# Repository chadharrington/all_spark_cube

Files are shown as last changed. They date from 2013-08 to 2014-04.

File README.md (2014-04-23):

## General Cube Info

The All Spark Cube was built in 2012-2013 by Adaptive Computing and friends. More 
info is available here:
* www.allsparkcube.com
* [Hackaday Article](http://hackaday.com/2012/10/21/4096-leds-means-the-biggest-led-cube-ever/)

## Cube Client Libraries

To interact with the All Spark Cube, you'll need a client library for your 
preferred programming language. There are currently cube client libraries 
available for Python and Java. Skip to the relevant section for your language.

### Python Client 

#### Usage
Here is the Python [Hello World](https://github.com/chadharrington/all_spark_cube/blob/master/software/clients/python_client/examples/helloworld.py) demo:
```
#!/usr/bin/env python

from all_spark_cube_client import CubeClient, Color, Colors

#HOST = 'localhost'
HOST = 'cube.ac'
PORT = 12345

client = CubeClient(HOST, PORT)

# Built-in colors are: red, green, blue, yellow, cyan, magenta, 
# white, black, gray, orange, pink, light_yellow, and dark_green
# You can also create any arbitrary color by creating an instance 
# of the Color class with the R, G, and B values specified.

# Set all LEDs to blue. 
client.set_all_leds(Colors.blue)

# Set the first LED (#0) to red
client.set_led(0, Colors.red)

# Set the second LED (#1) to a custom color (teal-ish)
client.set_led(1, Color(100, 255, 95))

# Starting at LED #48, set 16 LEDs to yellow
client.set_led_range(48, 16, Colors.yellow)

# Set the last LED (#4095) to green
client.set_led(4095, Colors.green)

# Actually send the data to the cube
client.send();  

print 'Success...'
```

#### Installation

Install the [Python client library](https://pypi.python.org/pypi/all_spark_cube_client/)
using pip. If you don't have pip installed, get it 
[here.](http://www.pip-installer.org/en/latest/installing.html)

`$ pip install all_spark_cube_client`

You can safely ignore the 10 or so warnings generated by pip, these are a 
part of the underlying [Thrift](http://thrift.apache.org/) library, and don't
affect the cube client library.

Download the code and run the [Hello World](https://github.com/chadharrington/all_spark_cube/blob/master/software/clients/python_client/examples/helloworld.py) demo on the cube:

```
$ wget -O helloworld.py http://git.io/hellopycube
$ python helloworld.py
```

You should see the cube change colors as specified in the program (first LED 
red, second LED teal, a row of yellow LEDs, etc.) You should see 
"Success..." on your command line. If you get errors instead, open the 
helloworld.py file and make sure the HOST 
parameter is set to the correct network address for the cube. You should also
make sure the cube is turned on and reachable over the network.

### Java Client 

#### Usage
The Java [Hello World](https://github.com/chadharrington/all_spark_cube/blob/master/software/clients/java_client/examples/HelloWorld.java) demo is below. Note that the API uses the [java.awt.Color](http://docs.oracle.com/javase/7/docs/api/java/awt/Color.html) class to specify colors for the LEDs.
```
import java.awt.Color;

import com.allsparkcube.CubeClient;
import org.apache.thrift.TException;

public class HelloWorld {
    public static void main(String[] args) {
        try {

            // final String HOST = "localhost";
            final String HOST = "cube.ac";
            final int PORT = 12345;
        
            CubeClient client = new CubeClient(HOST, PORT);

            // Set all LEDs to blue
            client.setAllLeds(Color.white); 

            // Set the first LED (#0) to red
            client.setLed(0, Color.red);

            // Set the second LED (#1) to a custom color (teal-ish)
            Color teal = new Color(100, 255, 95);
            client.setLed(1, teal);
        
            // Starting at LED #48, set 16 LEDs to yellow
            client.setLedRange(48, 16, Color.yellow); 

            // Set the last LED (#4095) to green
            client.setLed(4095, Color.green);
        
            // Actually send the data to the cube
            client.send();  
        
            System.out.println("Success...");
        } catch (TException e) {
            e.printStackTrace();
        }
    }
}

``` 

#### Installation
You can install and use the Java client with or without Maven.

##### Using Maven
Clone the git repository, then build  and run the [Hello World](https://github.com/chadharrington/all_spark_cube/blob/master/software/clients/java_client/examples/HelloWorld.java) example using Maven:

```
$ git clone https://github.com/chadharrington/all_spark_cube.git
$ cd all_spark_cube/software/clients/java_client/examples/
$ mvn package
$ cd target/com/mycompany
$ java -cp hello-world-0.1-standalone.jar HelloWorld
```
You should see the cube change colors as specified in the program (first LED 
red, second LED teal, a row of yellow LEDs, etc.) You should see 
"Success..." on your command line. If you get errors instead, open the 
HelloWorld.java file and make sure the HOST 
parameter is set to the correct network address for the cube. You should also
make sure the cube is turned on and reachable over the network.

#### Direct Download 
If you don't use Maven, you can download the client jar and [Hello World](https://github.com/chadharrington/all_spark_cube/blob/master/software/clients/java_client/examples/HelloWorld.java) example directly from GitHub:

```
$ wget http://git.io/cubejar -O cube_client-0.6-standalone.jar
$ wget http://git.io/hellojavacube -O HelloWorld.java 
$ javac -cp .:cube_client-0.6-standalone.jar HelloWorld.java
$ java -cp .:cube_client-0.6-standalone.jar HelloWorld
```

You should see the cube change colors as specified in the program (first LED 
red, second LED teal, a row of yellow LEDs, etc.) You should see 
"Success..." on your command line. If you get errors instead, open the 
HelloWorld.java file and make sure the HOST 
parameter is set to the correct network address for the cube. You should also
make sure the cube is turned on and reachable over the network.

## Cube Server Install
These instructions are only relevant for installing the server onto the computer 
inside the All Spark Cube. Cube users need not install the server code.

The server code and these instructions assume a CentOS / RHEL server.

1 - Install supervisor from http://supervisord.org
2 - Run these commands:

```    
$ git clone https://github.com/chadharrington/all_spark_cube.git
$ cd all_spark_cube/software/server
$ sudo make install
$ sudo reboot now
```

The server will automatically start on reboot / powerup. If everything installed
correctly, the cube should display all white LEDs after booting.

## Support

Having trouble? [Open an issue](https://github.com/chadharrington/all_spark_cube/issues).

## License

All code in this repository is licensed under an MIT license.

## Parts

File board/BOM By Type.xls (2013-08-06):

RefDes | Quantity | Digikey PN | Type | Value | Manufacturer | Manufacturer PN
C3, C4, C5, C6, C25, C26 | 26 | 399-8140-1-ND | CAP_1206 | 0.1 uF | Keme | C1206C104K3RACTU
C27 | 1 | 399-1255-1-ND | CAP_1206 | 1 uF | Keme | C1206C105K3RACTU
C28 | 1 | 399-10116-1-ND | CAP_1206 | 10 uF Tantalum | Kemet | T491A106K006AT7280
D1, D2, D3, D4 | 4 | 67-1685-1-ND | GRN SMD LED |  | Lumex | SML-LX15GC-TR
F1 | 1 | 3544-2K-ND | Fuse Holder |  | Keystone Electronics | 3544-2
H1, H2, H3, H4 | 4 |  | 0.125 Mnt Hole
J2, J3, J13, J14, J15, J16 | 16 |  | 0.1SMT 2x8ML |  | Samtec | TSM-108-0-S-DV
J17 | 1 | WM7243-ND | 6POS PWR JACK |  | Molex | 39294069
Q1, Q2, Q3, Q4, Q5, Q6, Q7, Q8, Q9, Q10, Q11, Q12, Q13, Q14, Q15, Q16 | 16 | FDS4465CT-ND | PFET |  | Fairchild Semiconductor | FDS4465
R7, R8, R9, R10 | 24 | 311-158FRCT-ND | RES_1206 | 158R | Yageo | RC1206FR-07158RL
R25, R26 | 2 | RMCF1206FT100KCT-ND | RES_1206 | 100K | Stackpole Eletronic | RMCF1206FT100K
R27 | 1 | 311-1.47KFRCT-ND | RES_1206 | 1K47 | Yageo | RC1206FR-071K47L
R28 | 1 | RMCF1206FT324RCT-ND | RES_1206 | 324R | Stackpole Eletronic | RMCF1206FTxxxx
R29, R30 | 2 | RMCF1206FT499RCT-ND | RES_1206 | 499R | Stackpole Eletronic | RMCF1206FTxxxx
R31 | 1 | RMCF1206FT105RCT-ND | RES_1206 | 105R | Stackpole Eletronic | RMCF1206FTxxxx
R32 | 1 | RMCF1206FT140RCT-ND | RES_1206 | 140R | Stackpole Eletronic | RMCF1206FT140R
RN1, RN2 | 8 | 4816P-1-100LFCT-ND | Resistor Pack | 10R | Bourns, Inc. | 4816P-1-100LF
RN9, RN10 | 2 | 4816P-1-104LFCT-ND | Resistor Pack | 100K | Bourns | 4816P-1-104LF
S1, S2, S3, S4 | 4 | SW1030CT-ND | Rotary Hex Switch |  | Omron | A6RS-161RS-P
U4, U5, U6, U7 | 24 | 296-21995-1-ND | TLC5917 |  | TI | TLC5917IDR
U25, U26, U27 | 3 | 296-21928-1-ND | Level Tranaslator |  | TI | TXB0104DR
U28 | 1 | P0082-ND | DE0-Nano |  | Terasic | P0082
U29 | 1 | 555-1051-ND | 3A Adj POL |  | Lineage Power | AXA003A0XZ
U30 | 1 | 941-1045-ND | 40A Adj POL |  | Delta | D12F200A
U31 | 1 | 768-1103-ND | UM232H |  | FTDI | UM232H
 | 147

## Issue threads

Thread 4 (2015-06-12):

Help

petreg, 2015-06-12:
First, sorry, my English is very bad and I'm using Google translator.
I would like to know how to assemble the circuit LEDs. I can not understand how to put together the 4096 leds with all RGBs connector. And I want to take a doubt, the data in this Github project, he used to program the de0-nano also? Yes I know I just need to ask you build a cube allspak for me, but if you can help me I would create a allsaprk for me.
>Thank you.

chadharrington, 2015-06-12:
Hi @petreg,
Building a large cube like we did might not be a good idea.  The 16x16x16 RGB cube cost around $10K to build and took a man-year or more. We also don't have time to document the build process, as it is very complicated. Here are some other LED cube projects with very good documentation:
- 4x4x4 RGB cube: http://www.instructables.com/id/4x4x4-RGB-LED-Cube/?ALLSTEPS
- 8x8x8 monochrome cube: http://www.instructables.com/id/Led-Cube-8x8x8/?ALLSTEPS
- 8x8x8 RGB cube: http://www.instructables.com/id/8X8X8-RGB-LED-Cube/?ALLSTEPS

Closed 2015-06-12.

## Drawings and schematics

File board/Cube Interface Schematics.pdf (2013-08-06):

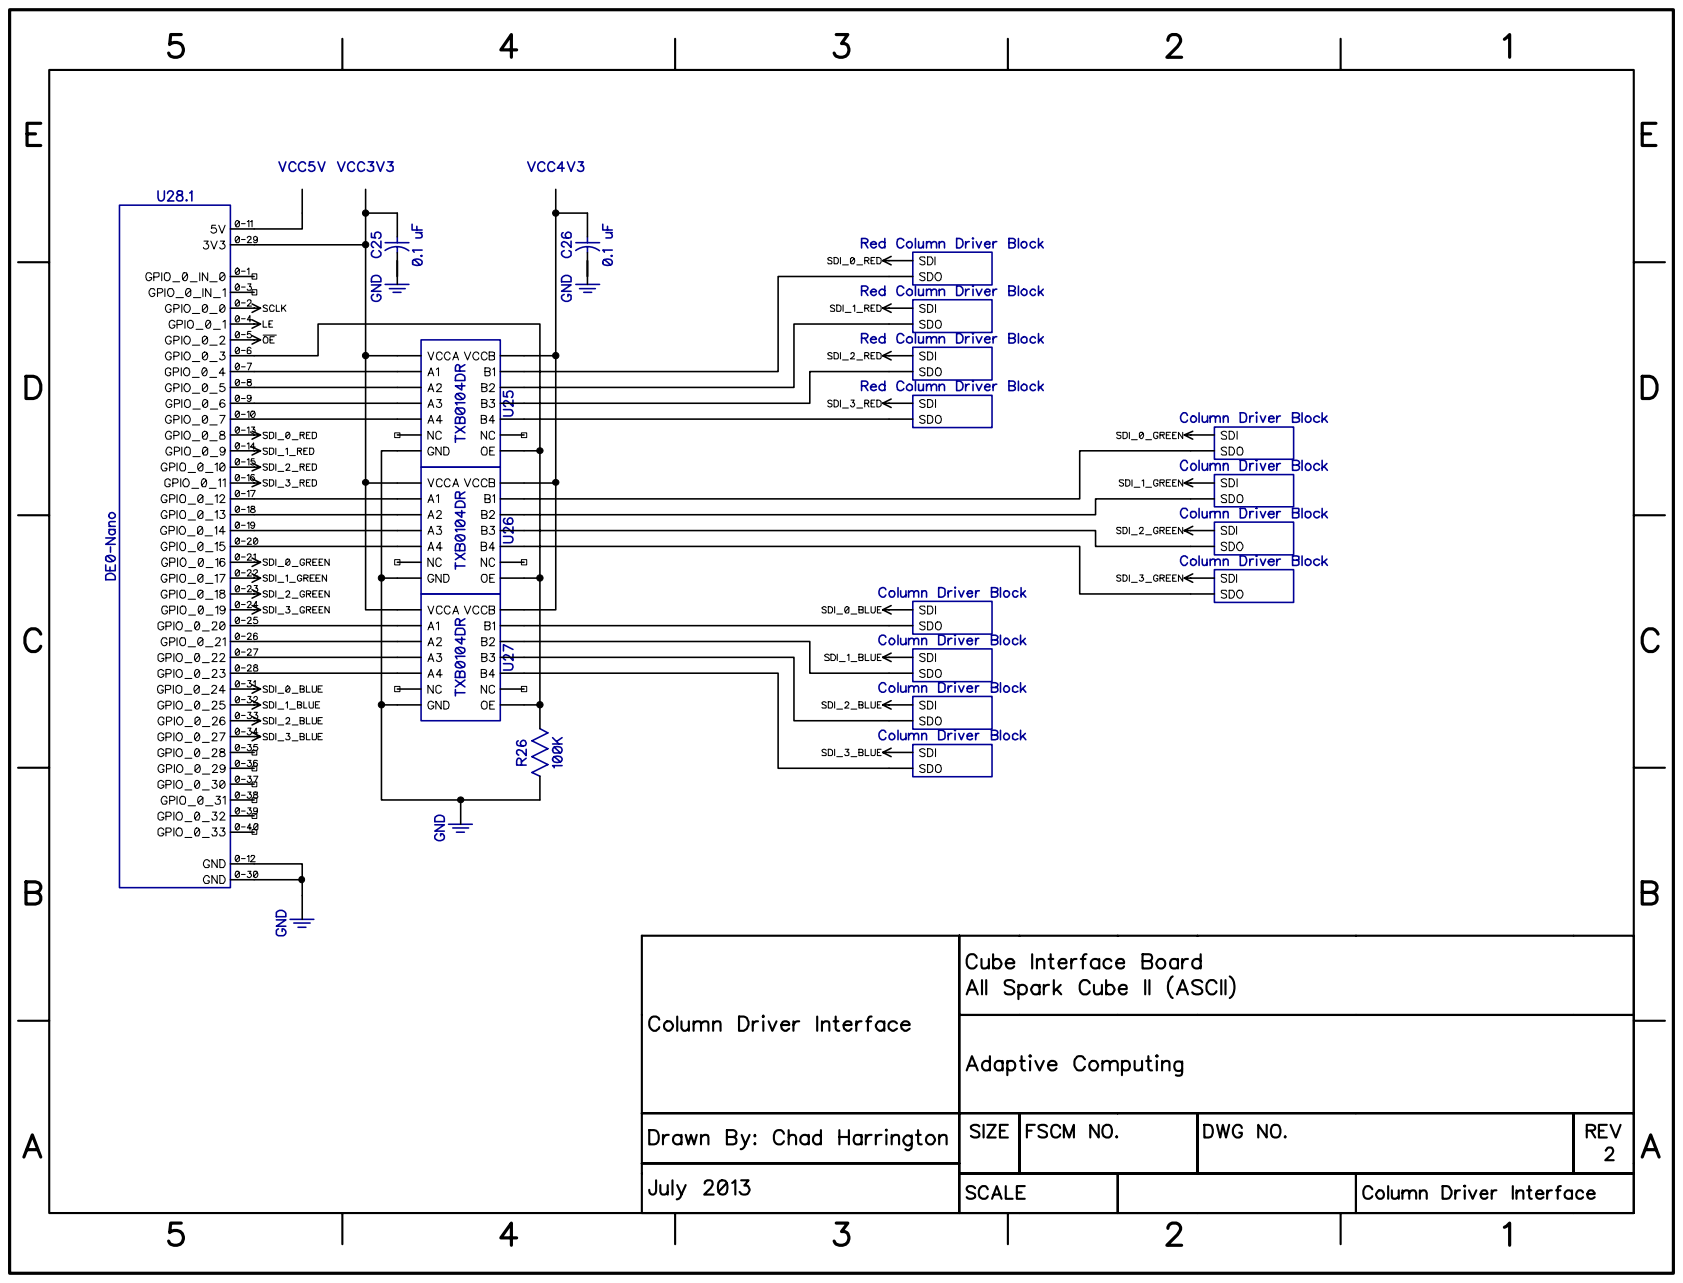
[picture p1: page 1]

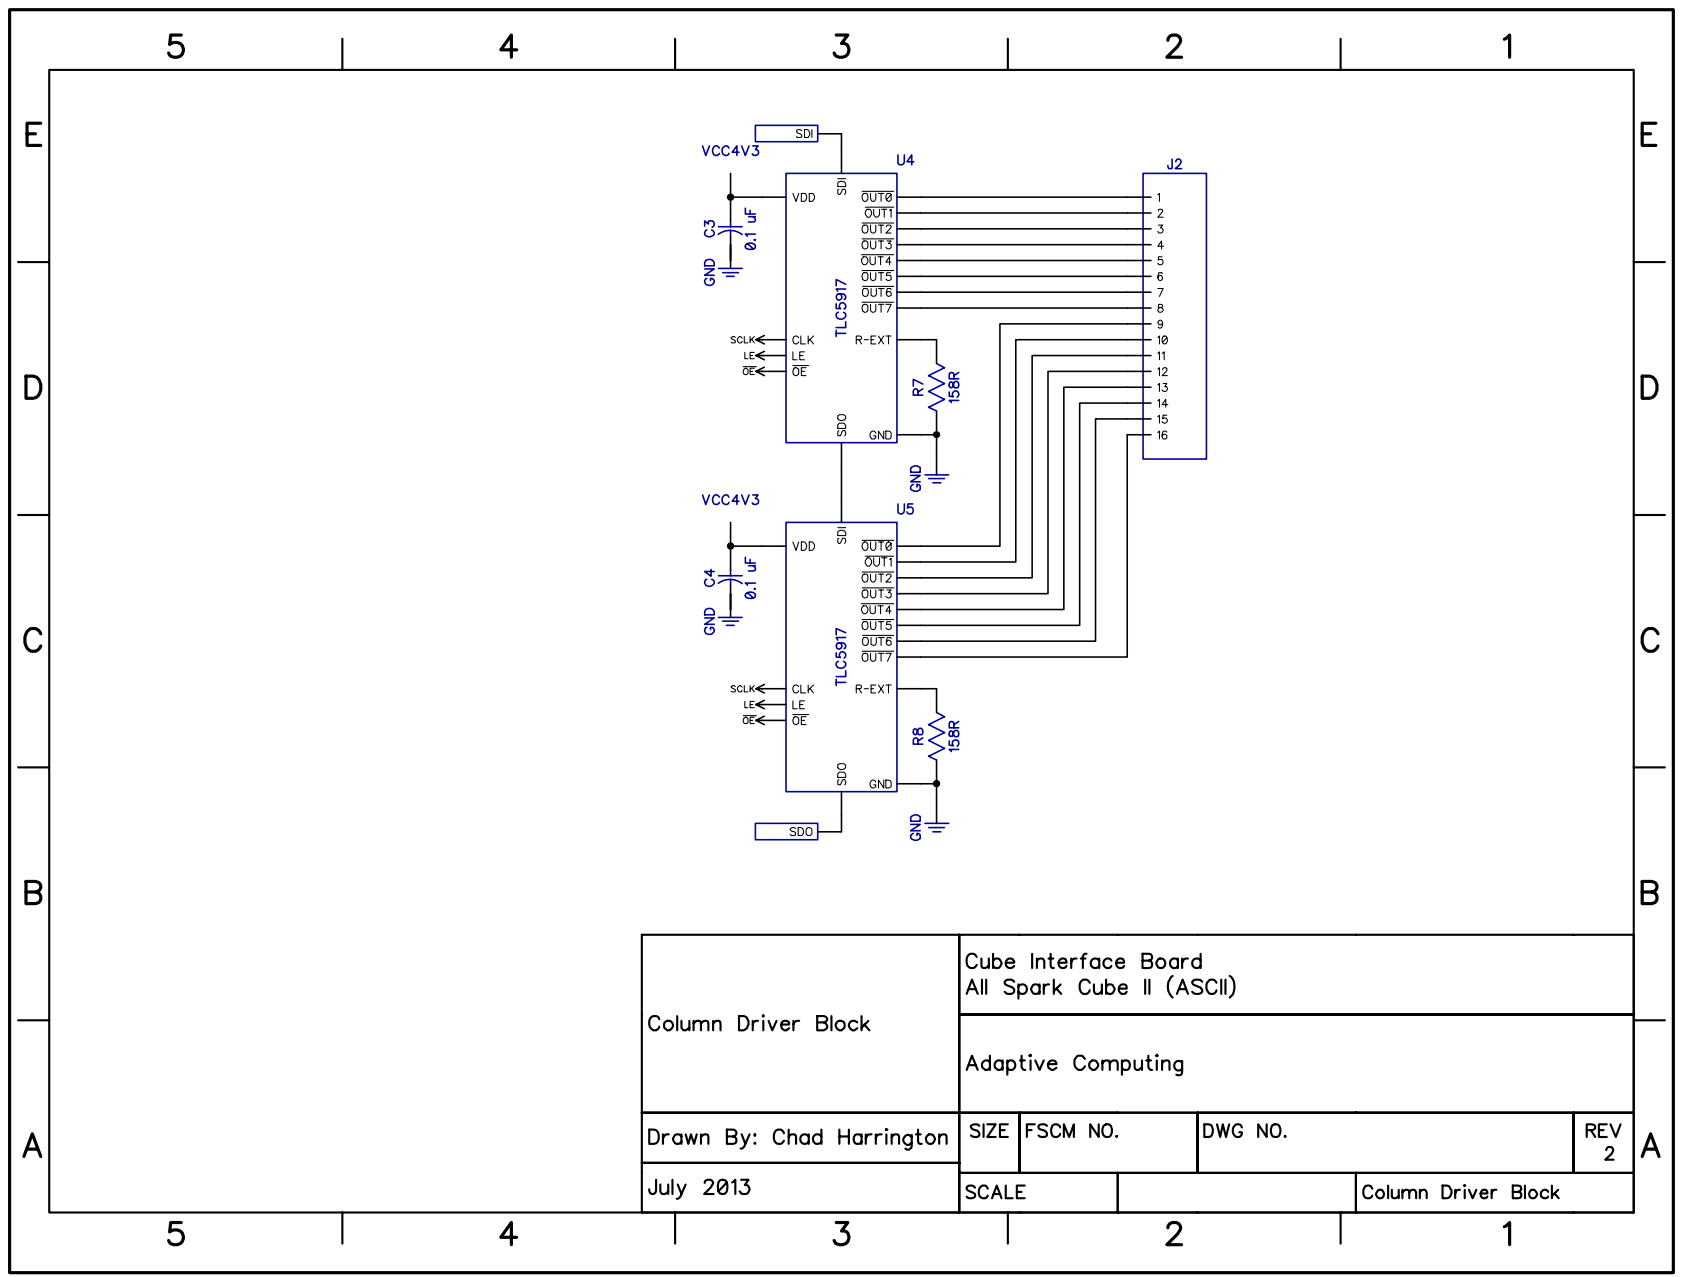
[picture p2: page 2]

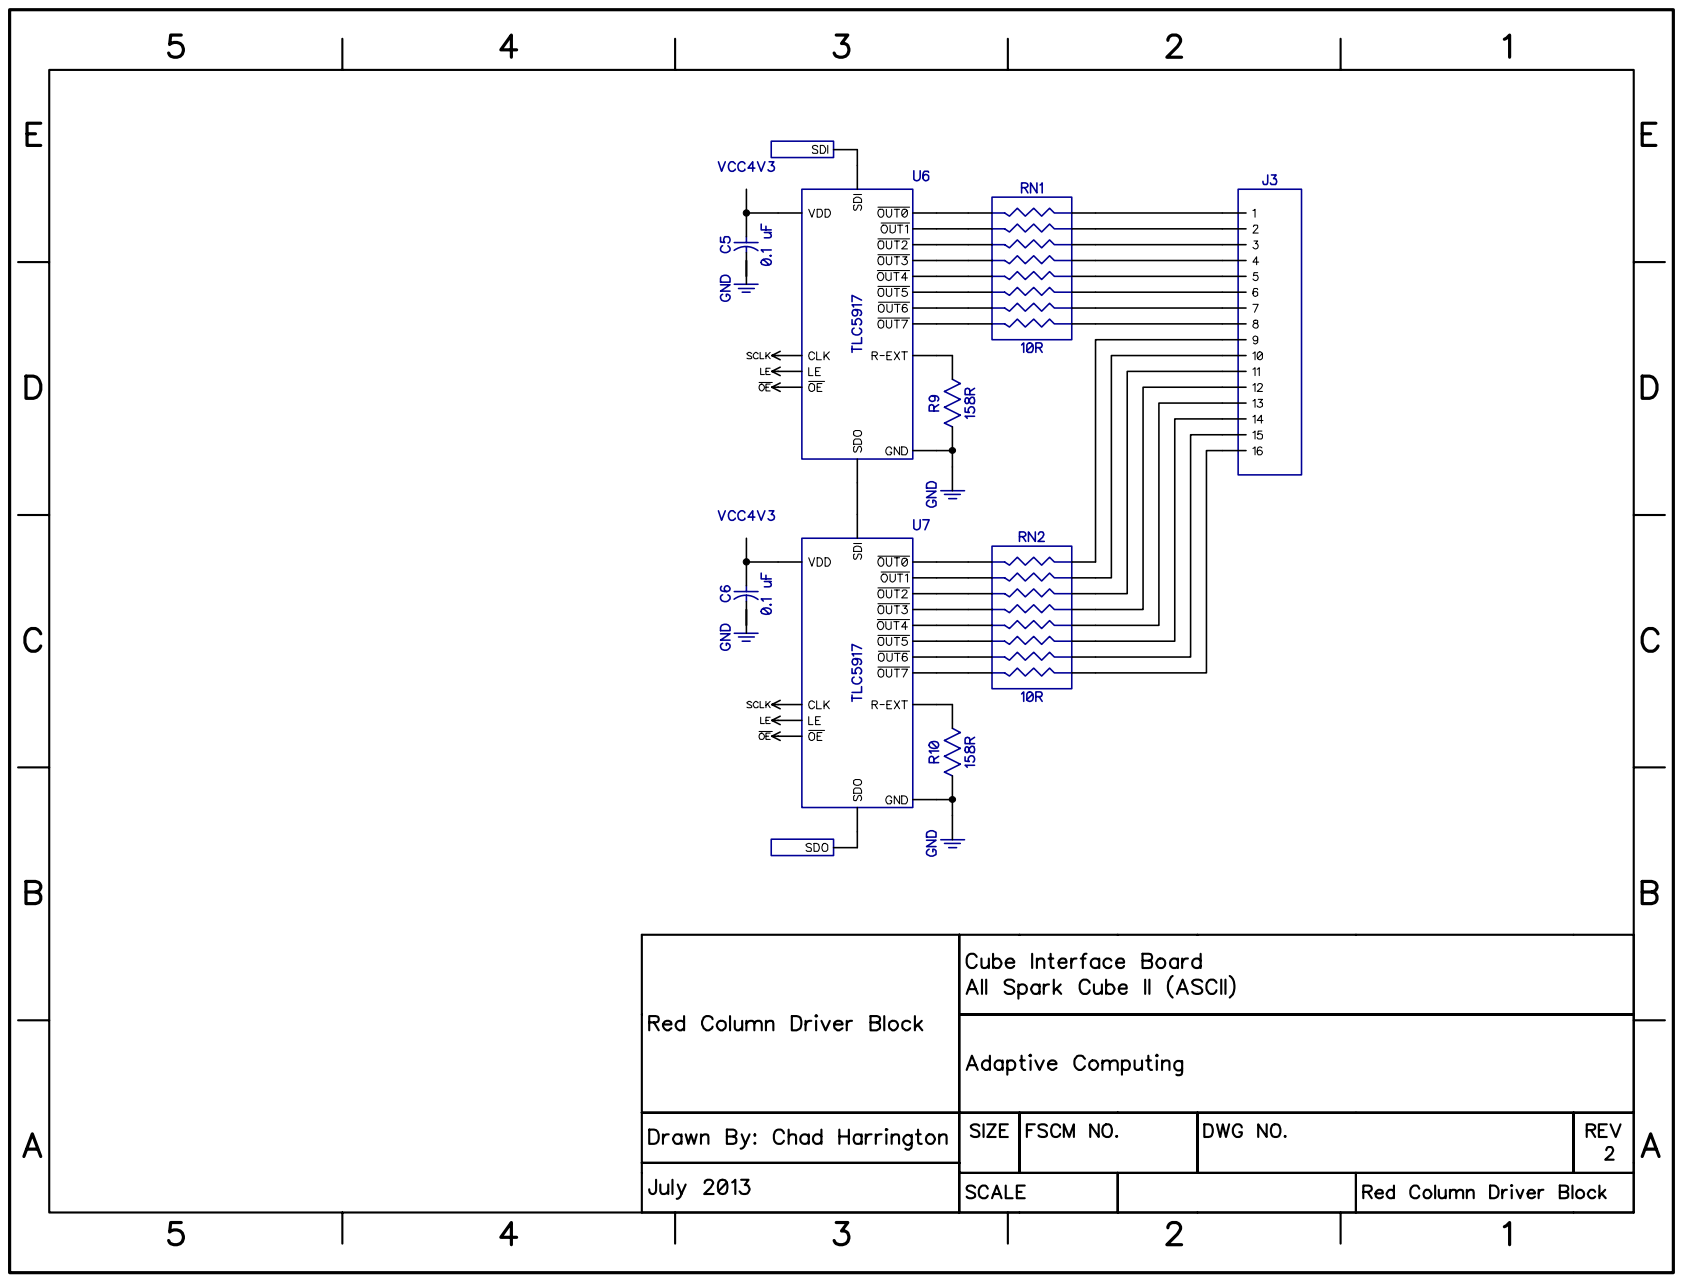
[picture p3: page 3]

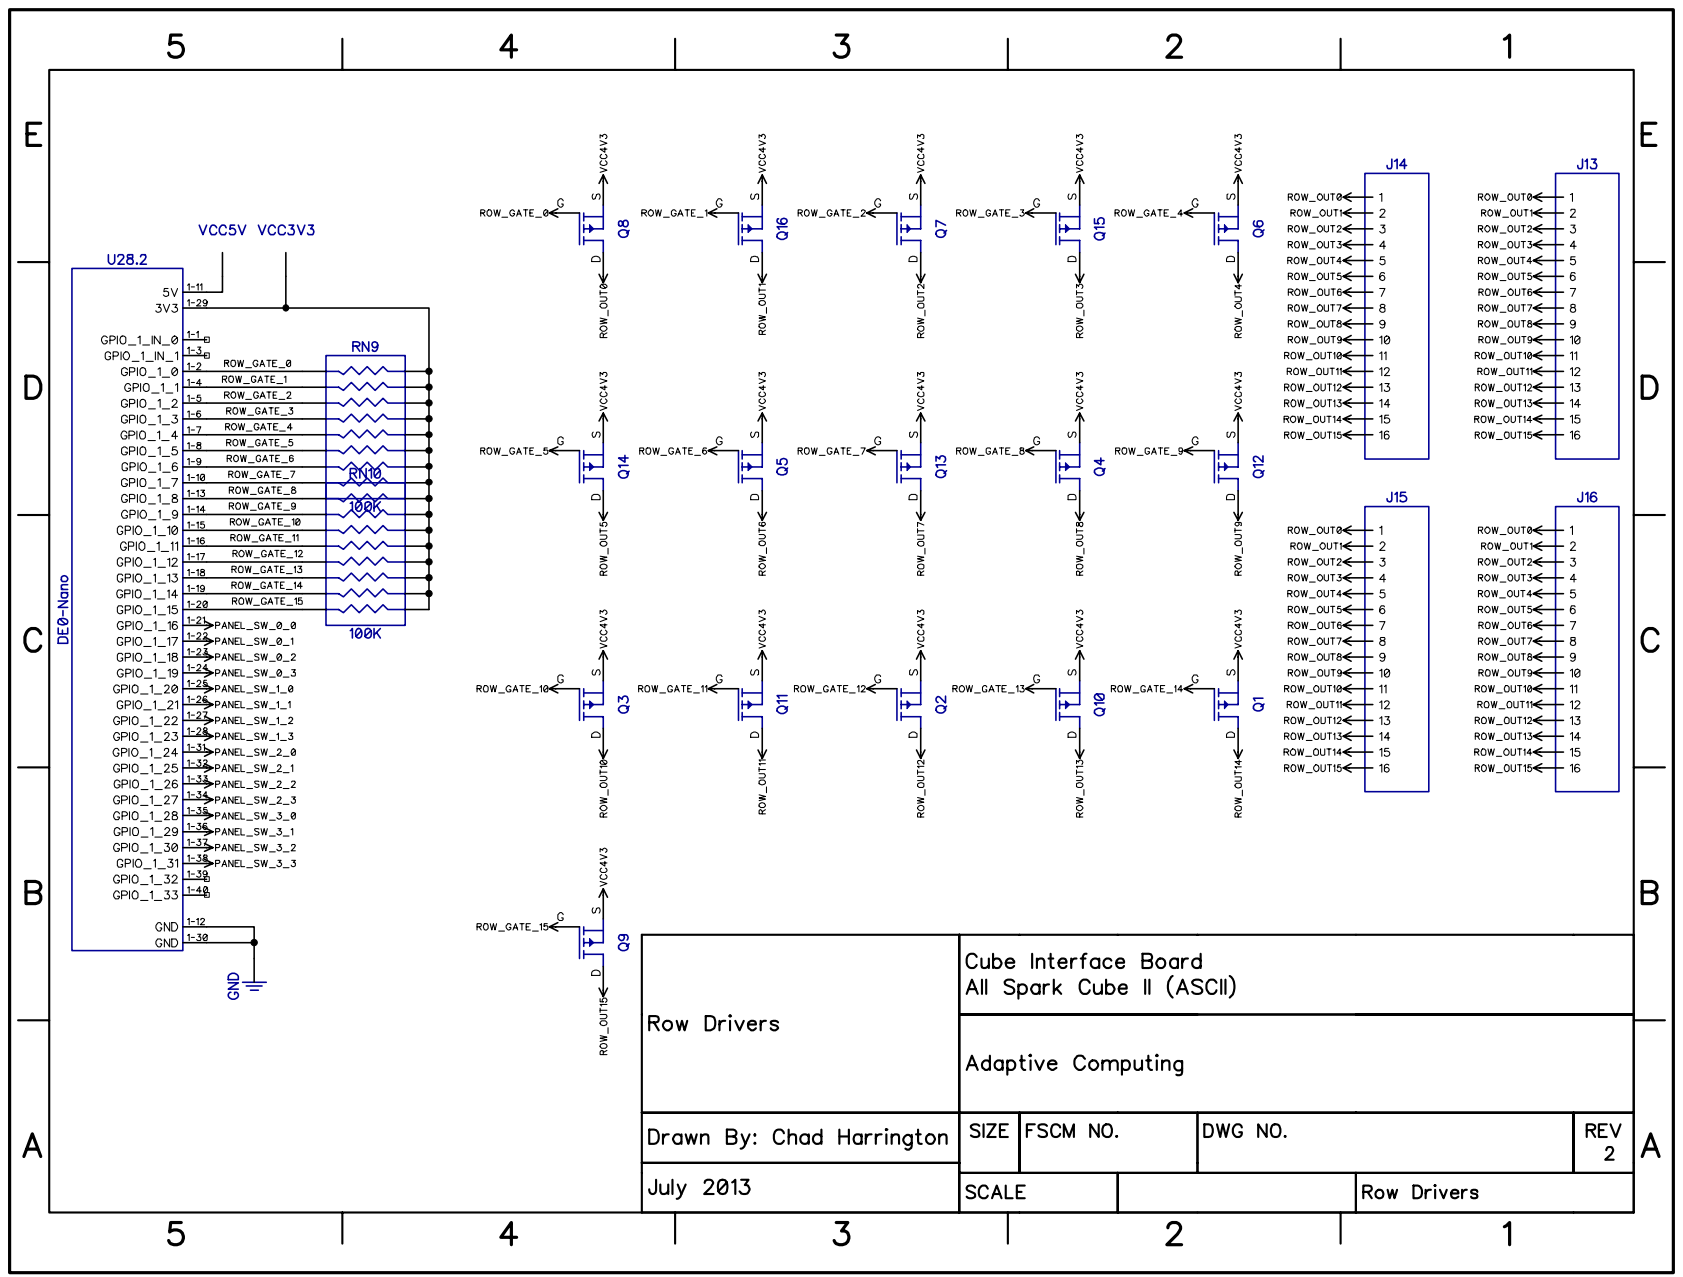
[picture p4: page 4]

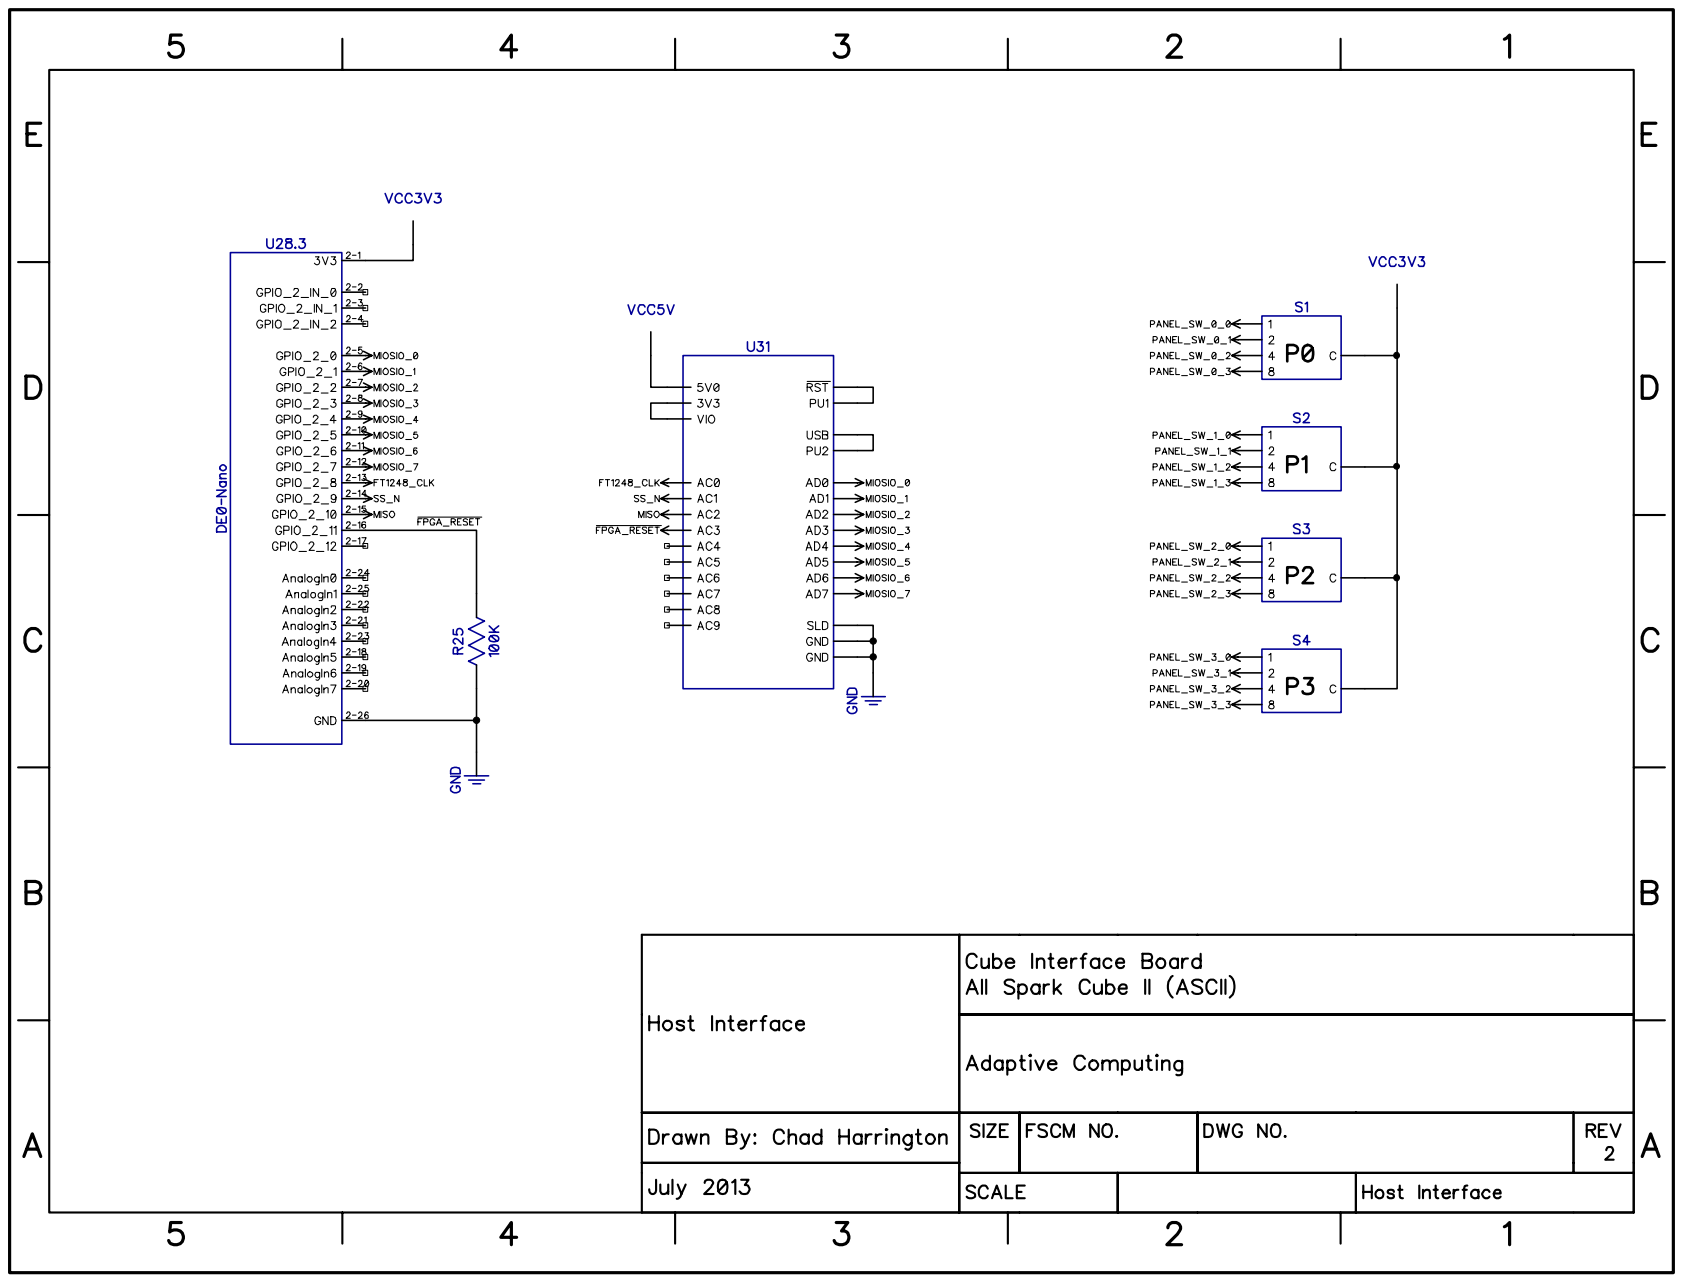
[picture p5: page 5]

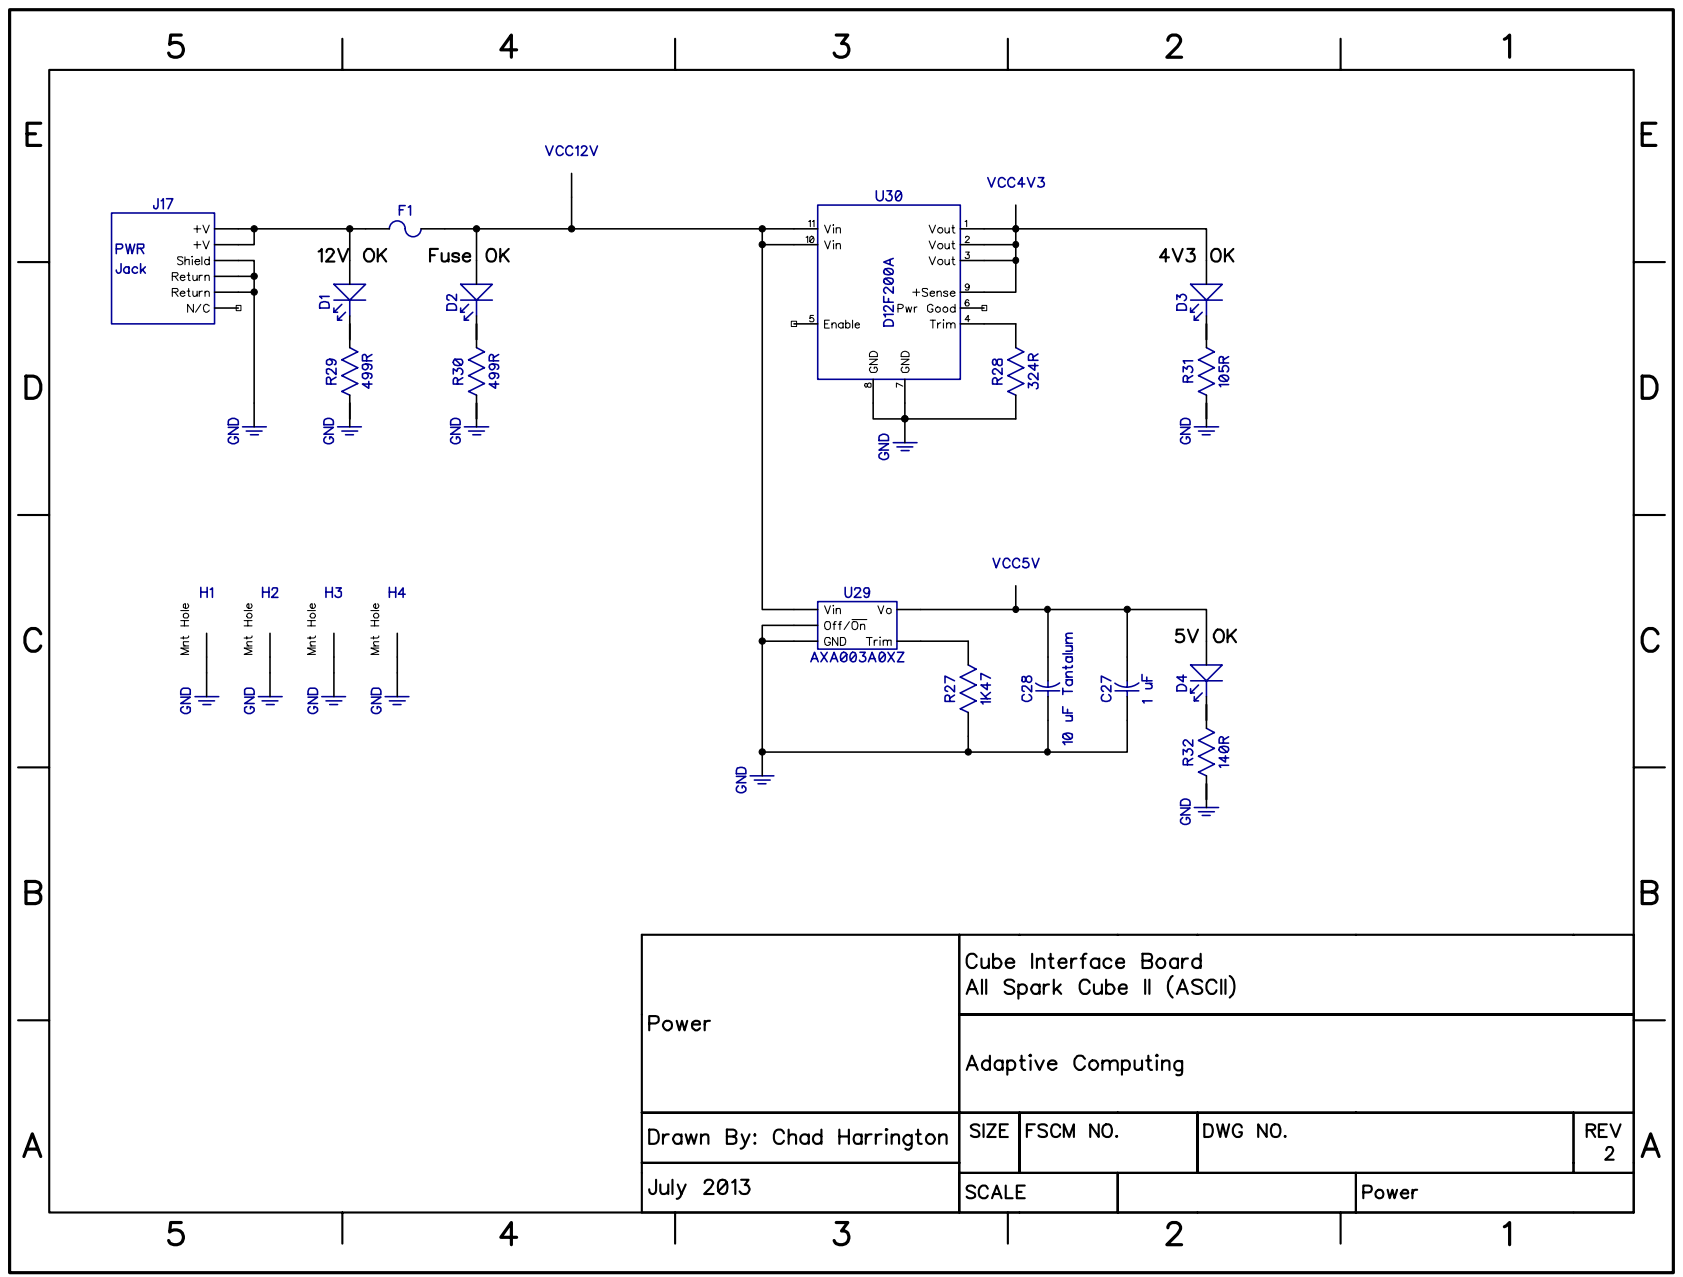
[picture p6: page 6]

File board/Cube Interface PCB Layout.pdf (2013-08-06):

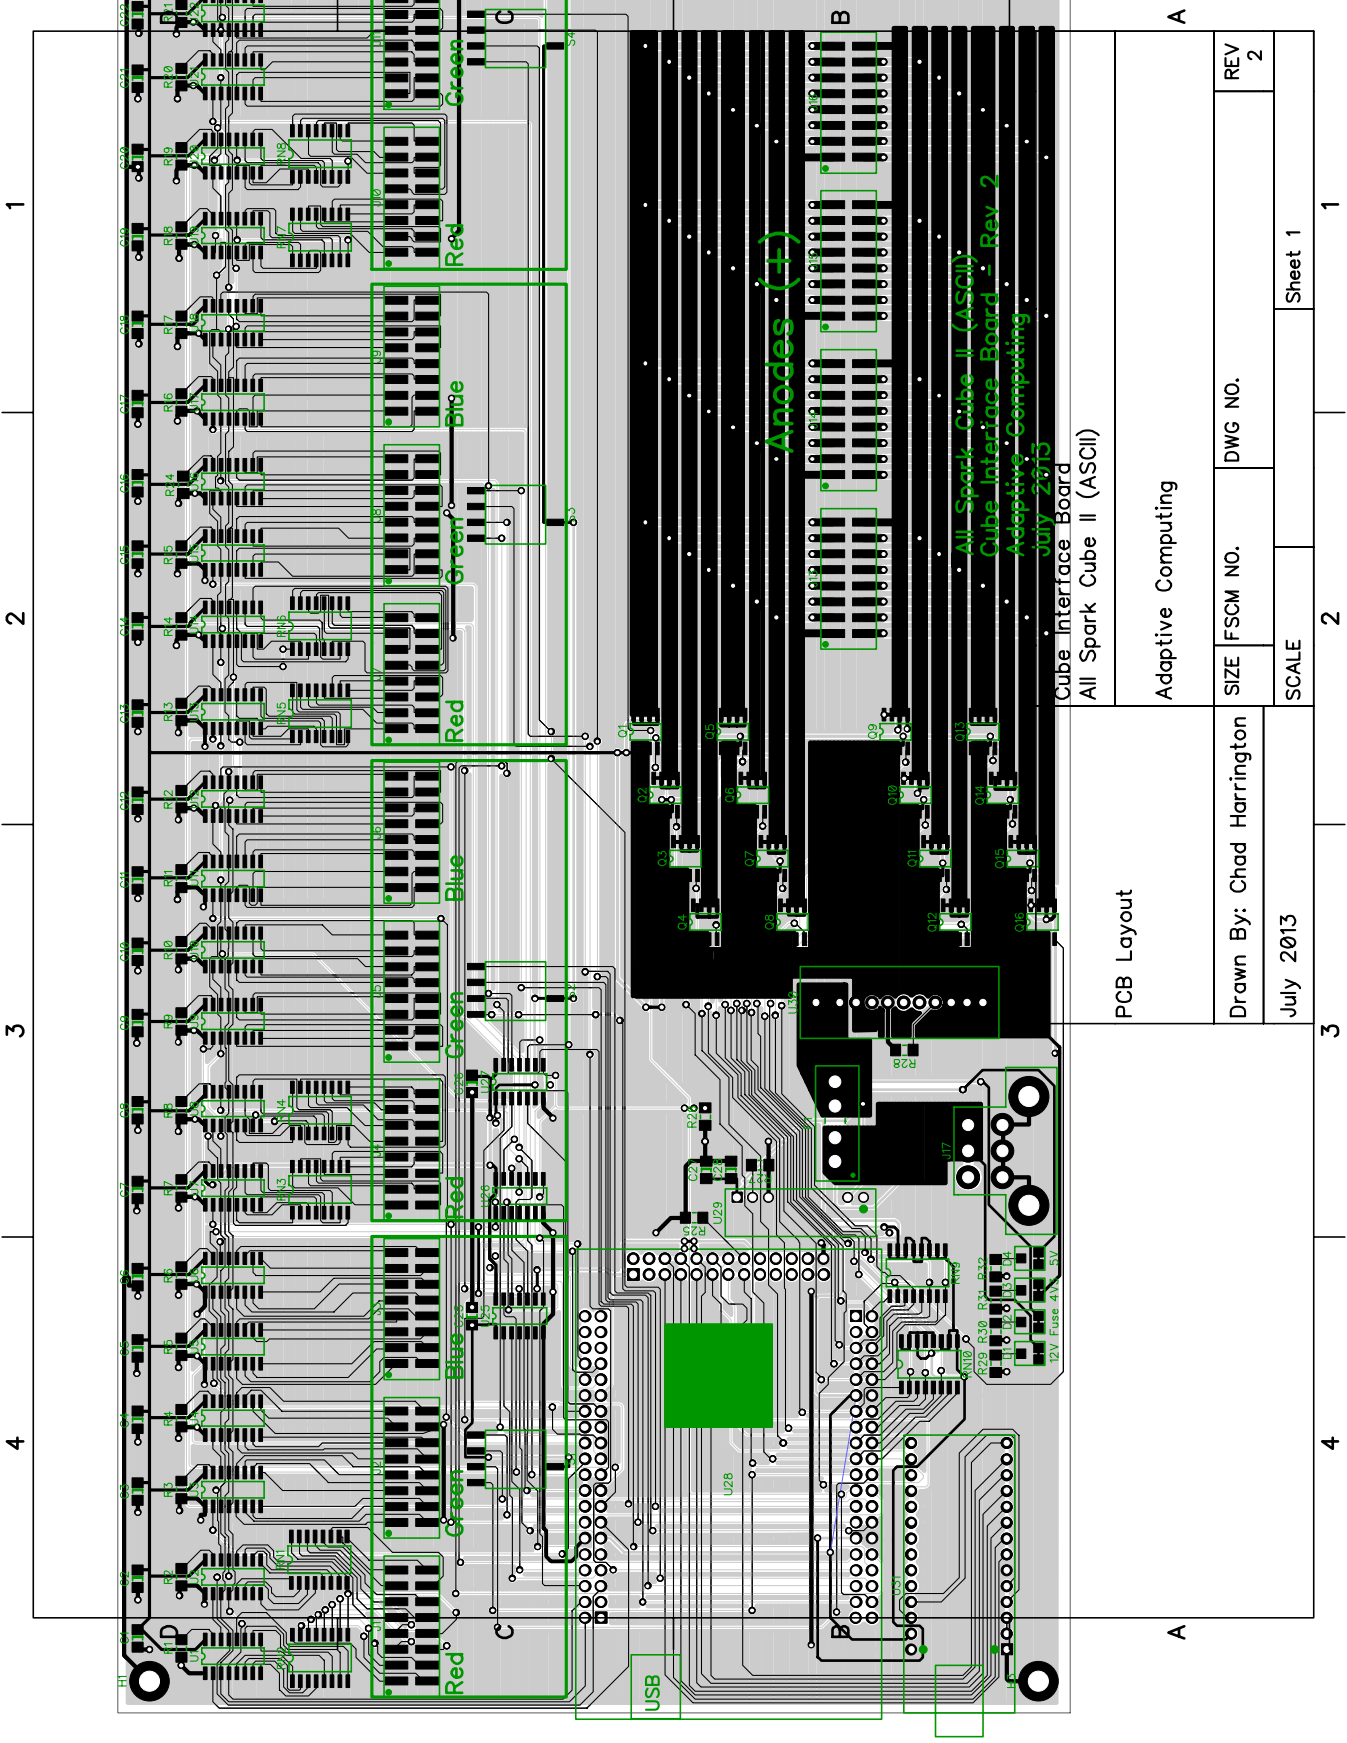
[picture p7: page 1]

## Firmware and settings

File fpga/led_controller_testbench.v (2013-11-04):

`timescale 1ns / 10ps

module led_controller_testbench;

   reg         clk;
   reg         reset_n;
   reg         test_panel_select_n;
   reg [31:0]  chunk_data;
   reg [3:0]   chunk_addr;
   reg         chunk_write_enable;
   reg [3:0]   row_addr;
   reg [1:0]   panel_addr;
   wire        serial_clk;
   wire        latch_enable;
   wire        output_enable_n;
   wire [11:0] serial_data_out;
   wire [15:0] row_select_n;

   led_controller uut
     (.clk(clk), .reset_n(reset_n), .test_panel_select_n(test_panel_select_n),
      .chunk_data(chunk_data), .chunk_addr(chunk_addr),
      .chunk_write_enable(chunk_write_enable), .row_addr(row_addr),
      .panel_addr(panel_addr), .serial_clk(serial_clk), 
      .latch_enable(latch_enable), .output_enable_n(output_enable_n),
      .serial_data_out(serial_data_out), .row_select_n(row_select_n)
      );

   always begin  // 50MHz clock
      clk = 1'b1;
      #10;
      clk = 1'b0;
      #10;
   end

   initial begin
      reset_n = 1'b0;
      test_panel_select_n = 1'b0;
      chunk_data = 32'hffffffff;
      chunk_addr = 4'h0;
      chunk_write_enable = 1'b0;
      row_addr = 4'h0;
      panel_addr = 2'h3;
      #100;
      
      reset_n = 1'b1;
      #200;

      chunk_write_enable = 1'b1;
      #40;

      chunk_write_enable = 1'b0;
      #660;
      
      $stop;
   end // initial begin

endmodule // led_controller_testbench

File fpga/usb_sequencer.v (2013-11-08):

module usb_sequencer
  (
   input            clk,
   input            reset_n,
   input            rxf_n,
   input            txe_n,
   input            panel_select_request,
   input [15:0]     panel_switches,
   output reg [7:0] data_out,
   output           rd_n,
   output           wr_n, 
   output           data_out_enable,
   output           command_write_enable,
   output           clear_psr, 
   output [4:0]     state_out
   );

   reg [4:0]        state, next_state, output_bits;

   assign state_out = state;
   assign rd_n = output_bits[4];
   assign wr_n = output_bits[3];
   assign data_out_enable = output_bits[2];
   assign command_write_enable = output_bits[1];
   assign clear_psr = output_bits[0];
   
   // Labeled states
   localparam [4:0] 
     start_read = 5'd0,
     end_read = 5'd7,
     start_write = 5'd8,
     write_p1 = 5'd13,
     write_p2 = 5'd18,
     write_p3 = 5'd23,
     end_write = 5'd28;

   // State register
   always @(posedge clk, negedge reset_n)
     if (!reset_n)
       state <= start_read;
     else
       state <= next_state;

   // Next state logic
   always @(*)
     case (state)
       start_read:          
         if (panel_select_request)
           next_state = start_write;
         else
           if (rxf_n) 
             next_state = start_read;
           else 
             next_state = state + 1'b1;
       end_read:
         if (panel_select_request)
           next_state = start_write;
         else
           next_state = start_read;
       start_write:
         if (txe_n)
           next_state = start_write;
         else
           next_state = state + 1'b1;
       write_p1:
         if (txe_n)
           next_state = write_p1;
         else
           next_state = state + 1'b1;
       write_p2:
         if (txe_n)
           next_state = write_p2;
         else
           next_state = state + 1'b1;
       write_p3:
         if (txe_n)
           next_state = write_p3;
         else
           next_state = state + 1'b1;
       end_write:
         next_state = start_read;
       default:
         next_state = state + 1'b1;
     endcase // case (state)

   // Output logic
   always @(*)
     if (!reset_n)
       begin
          data_out = 8'hzz;
          output_bits = 4'b1100;
       end
     else
       case (state)
         0: // start_read
           begin
              data_out = 8'hzz;
              output_bits = 5'b11000;
           end
         1: // 
           begin
              data_out = 8'hzz;
              output_bits = 5'b01000;
           end
         2: // 
           begin
              data_out = 8'hzz;
              output_bits = 5'b01000;
           end
         3: // 
           begin
              data_out = 8'hzz;
              output_bits = 5'b01000;
           end
         4: // 
           begin
              data_out = 8'hzz;
              output_bits = 5'b11010;
           end
         5: // 
           begin
              data_out = 8'hzz;
              output_bits = 5'b11000;
           end
         6: // 
           begin
              data_out = 8'hzz;
              output_bits = 5'b11000;
           end
         7: // end_read
           begin
              data_out = 8'hzz;
              output_bits = 5'b11000;
           end
         8: // start_write
           begin
              data_out = 8'hzz;
              output_bits = 5'b11000;
           end
         9: // 
           begin
              data_out = {4'h1, panel_switches[3:0]};
              output_bits = 5'b11100;
           end
         10: // 
           begin
              data_out = {4'h1, panel_switches[3:0]};
              output_bits = 5'b10100;
           end
         11: // 
           begin
              data_out = {4'h1, panel_switches[3:0]};
              output_bits = 5'b10100;
           end
         12: // 
           begin
              data_out = {4'h1, panel_switches[3:0]};
              output_bits = 5'b11100;
           end
         13: // write_p1
           begin
              data_out = {4'h1, panel_switches[3:0]};
              output_bits = 5'b11100;
           end
         14: // 
           begin
              data_out = {4'h2, panel_switches[7:4]};
              output_bits = 5'b11100;
           end
         15: // 
           begin
              data_out = {4'h2, panel_switches[7:4]};
              output_bits = 5'b10100;
           end
         16: // 
           begin
              data_out = {4'h2, panel_switches[7:4]};
              output_bits = 5'b10100;
           end
         17: // 
           begin
              data_out = {4'h2, panel_switches[7:4]};
              output_bits = 5'b11100;
           end
         18: // write_p2
           begin
              data_out = {4'h2, panel_switches[7:4]};
              output_bits = 5'b11100;
           end
         19: // 
           begin
              data_out = {4'h3, panel_switches[11:8]};
              output_bits = 5'b11100;
           end
         20: // 
           begin
              data_out = {4'h3, panel_switches[11:8]};
              output_bits = 5'b10100;
           end
         21: // 
           begin
              data_out = {4'h3, panel_switches[11:8]};
              output_bits = 5'b10100;
           end
         22: // 
           begin
              data_out = {4'h3, panel_switches[11:8]};
              output_bits = 5'b11100;
           end
         23: // write_p3
           begin
              data_out = {4'h3, panel_switches[11:8]};
              output_bits = 5'b11100;
           end
         24: // 
           begin
              data_out = {4'h4, panel_switches[15:12]};
              output_bits = 5'b11100;
           end
         25: // 
           begin
              data_out = {4'h4, panel_switches[15:12]};
              output_bits = 5'b10100;
           end
         26: // 
           begin
              data_out = {4'h4, panel_switches[15:12]};
              output_bits = 5'b10100;
           end
         27: // 
           begin
              data_out = {4'h4, panel_switches[15:12]};
              output_bits = 5'b11101;
           end
         28: // end_write
           begin
              data_out = {4'h4, panel_switches[15:12]};
              output_bits = 5'b11100;
           end
         default: // default
           begin
              data_out = 8'hzz;
              output_bits = 5'b11000;
           end
       endcase // case (state)

endmodule // usb_sequencer

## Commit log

2013-07-21 Basic LED control working
2013-07-24 Updated Controller Timing spreadsheet
    [Controller Timing.xls]
2013-07-24 Shell of board schematic created. Power section done.
    [Power Calculations.xls]
2013-07-24 Added Column Driver Blocks to schematic
2013-07-24 Connected column drivers to FPGA in schematic
2013-07-25 Minor schematic changes
2013-07-25 Added rotary hex switch to library
2013-07-25 Added datasheets for level translator and rotary hex switch
2013-07-25 Added symbols for level translator and rotary hex switch
2013-07-25 Schematic nearly done; need to add host interface
2013-07-25 Schematic release candidate 1 complete
2013-07-25 Updated 2x8 header footprint
2013-07-25 First cut layout
2013-07-25 Second cut layout
2013-07-26 Updated Fuse Holder pattern and symbol. Placed copper pours for 1/2 of row outs
2013-07-26 Added pullup resistors to row driver gates in schematic.
2013-07-26 Added ground connections to mounting holes
2013-07-26 Layout WIP. Power routed.
2013-07-26 Layout WIP. A few power fixes.
2013-07-27 Layout WIP. 1/4 of new driver placement done
2013-07-27 Layout WIP. 1/2 of new driver placement done
2013-07-27 PCB 100% routed.
2013-07-27 Renumbered RefDeses. Fixed J1 & J2 header placement. Some Silkscreen done.
2013-07-27 PCB RC1
2013-07-28 Added BOMs
    [Cube Interface BOM By PN.xls, Cube Interface BOM By Type.xls]
2013-07-28 Replaced rotary hex switch with a different model, since the other model was backordered.
2013-07-28 Expanded bottom copper pour to whole board
    [BoardOutline.gbr, Bottom.gbr, BottomMask.gbr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]
2013-07-29 Generated PCB manufactuing files
    [Cube Interface BOM By Type.xls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]
2013-07-31 Updated sequencer ROM to work with 16-bit blocks
    [Controller Timing.xls]
2013-08-06 Updated BOM
    [BOM By Type.xls, Controller Timing.xls, Cube Interface BOM By PN.xls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]
2013-08-06 Added PDF of board schematics
2013-08-06 Added PDF of PCB layout
2013-08-08 Changed out 1.8V PFET for a 2.5V PFET
2013-08-14 FPGA WIP
    [Power Calculations.xls]
2013-08-18 FPGA simple driver working
    [Controller Timing.xls]
2013-09-21 Discovered PCB layout mistakes, compensated by changing FPGA pin assignments. Fixed color now working.
2013-09-29 Fixed problems with 8x8 LED array pinout and 2x8 shrouded conn pinout.
2013-10-16 Set weak pullups on GPIO_1 pins to enable proper panel switch reading.
2013-10-16 Working column-level driver without adapter for test panels.
2013-10-16 Added test panel adapter to compensate for test panel wiring differences from cube
2013-10-17 Created stub for usb_controller; wired everything.
2013-10-22 FPGA coding WIP.
    [Controller Timing.xls, rom_states.xls, usb_sequencer_states.xls]
2013-10-23 FPGA coding feature complete. Not yet debugged.
    [usb_sequencer_states.xls]
2013-10-24 Added FTDI USB programming datasheet
    [usb_sequencer_states.xls]
2013-10-29 Driver software WIP
2013-10-29 Software driver WIP
2013-10-29 Fixed usb_sequencer bit ordering problem. Defined outputs during reset.
    [usb_sequencer.v]
2013-11-01 C Driver WIP
2013-11-01 Fixed bug in USB. assign statement was backwards on rd_n & wr_n lines.
    [usb_sequencer_states.xls]
2013-11-01 Changed FPGA to explicitly clear psr flag
    [usb_sequencer_states.xls]
2013-11-04 Software driver code complete.
2013-11-05 Increased send buffer size to increase frames per second.
2013-11-07 Updated driver Makefile
2013-11-07 Fixed bug where red and green colors were switched
2013-11-08 Fixed FPGA timing bug.
    [usb_sequencer_states.xls]
2013-11-11 Reorganized directories
    [Power Calculations.xls]
2013-11-13 Fixed major issue with ports 0 & 1 not working when 4 panels are connected. Solution: widen the SCLK pulses to the TLC chips. Timing was out of spec before.
    [rom_states.xls]
2013-11-15 First cut of tetris demo
2013-12-12 WIP: Rewriting server driver in C.
2013-12-12 Driver rewrite in C code complete
2013-12-12 Added command table to driver.c
2013-12-15 WIP on driver.c
2013-12-15 Rewrote USB driver in C; removed python USB driver
2013-12-15 changed all dirnames to lower case
    [BOM By Type.xls, Cube Interface BOM By PN.xls, Power Calculations.xls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]
2013-12-19 Added delay to driver thread startup
2013-12-19 Fixed supervisord.conf so that driver will start correctly
2013-12-19 Changed driver.c to cube_driver.c
2014-01-03 Added delay to driver loop
2014-02-10 Fix frame length issue
2014-02-11 Revert "Fix frame length issue"
    This reverts commit c16864ba6ce500e1f1821c3d902b25ed64ef187d.
